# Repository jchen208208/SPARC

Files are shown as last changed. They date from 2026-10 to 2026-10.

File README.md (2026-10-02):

# SPARC

SPARC

SPARC (Spotify Proximity and Remote Control) is a gesture controller for music. You wave a hand over it to skip tracks, pause, or change the volume, without touching a screen or a button. We built it for times when looking at your phone is inconvenient or unsafe, mainly adjusting music while driving.

The current version is an MVP: an ESP32 on a custom PCB, a time-of-flight distance sensor, an 8-LED strip and a LiPo battery, all inside a 3D-printed case we designed in CAD.

## How it works

SPARC pairs over Bluetooth Low Energy as a HID media remote, the same kind of device as the play/pause button on a pair of headphones. It never talks to Spotify. Each gesture sends a standard media key (next, previous, play/pause, volume up, volume down) to the operating system, and the OS passes it to whatever app is playing.

So there is no app to install and no Spotify login, and you don't need Premium. It works on iOS, Android, macOS, Windows and Linux, and with any media app: Spotify, Apple Music, YouTube or a podcast player. Like headphone buttons, it keeps working with the screen off and the phone in your pocket.

The HID report descriptor only declares media keys. Off-the-shelf ESP32 HID libraries present themselves as keyboards, and iOS hides the on-screen keyboard while any keyboard is connected, so you couldn't type in any app with SPARC paired.

## Gestures

The VL53L0X sensor points up and watches a zone from about 4 cm out to 30 cm. Each gesture is a pass, where your hand moves through the zone and out again, or a hold, where it stops inside it.

- One pass skips to the next track.
- Two quick passes go to the previous track.
- Holding your hand still for a moment toggles play/pause.
- Three quick passes enter volume mode.

Next and previous fire about 0.7 seconds after your last pass, because SPARC waits to see whether another pass is coming. In volume mode, the spot where your hand settles becomes the midpoint. Raise your hand above it to turn the volume up and lower it to turn the volume down; the volume keeps stepping while you stay off-center. To leave volume mode, pull your hand out of the zone or flick it up quickly.

If something stays still within a metre of the sensor for five seconds, like a car roof or a shelf, SPARC treats it as a back wall and ends the zone just short of it. With nothing in range, it falls back to the fixed 30 cm.

## Lights

The LED strip animates each gesture. A swipe runs one way for next and the other way for previous, the whole strip pulses for play/pause, and a looping sweep shows volume changes. A separate status LED flashes on play/pause.

On an iPhone, SPARC also reads what's playing through Apple Media Service and, between gestures, uses the strip as a progress bar for the current track. Other devices don't offer that service, so they only get the gesture animations.

## Hardware

- ESP32-WROOM-32 module, soldered straight onto the PCB (no devboard)
- VL53L0X time-of-flight distance sensor on I2C
- 8-LED WS2812B (NeoPixel) stick and a status LED
- Single-cell LiPo, charged through a TP4056, regulated to 3.3 V by an AP2112K
- Power slide switch, plus Reset and BOOT buttons
- 4-pin header for a CP2102 USB-serial adapter, used for flashing

The KiCad project for PCB v2 is in `pcb/`, along with a STEP model and `sparc_pcb_v2_gerbers.zip`, the Gerbers we sent to the fab. The case is two printable parts, `enclosure/SPARC_Base.stl` and `enclosure/SPARC_Lid.stl`.

PCB v1 is kept in `pcb/v1/`. Its Reset and BOOT buttons are wired across the power rail, so pressing one shorts 3.3 V to ground and the board can only be flashed with a jumper wire. `pcb/v1/PCB_V1_NOTES.md` covers that workaround and the other v1 bugs, all of which v2 fixes.

The battery level SPARC reports to your phone is hardcoded at 100%. The board doesn't measure it yet.

## Flashing

The firmware is `sketch_esp_hid_v2/sketch_esp_hid_v2.ino`. It needs the ESP32 Arduino core and three libraries: NimBLE-Arduino, Adafruit_VL53L0X and FastLED.

The sensor, LED strip and status LED sit on different pins on each board, so set `BOARD` at the top of the sketch before you build: `2` for PCB v2, `1` for PCB v1, `0` for the old perfboard. The wrong value builds fine, but the sensor and LEDs stay dead.

With the power switch on, connect a CP2102 adapter to the header (the adapter doesn't power the board), hold BOOT, tap Reset, then upload:

```bash
arduino-cli compile --fqbn esp32:esp32:esp32 --port /dev/cu.usbserial-0001 --upload sketch_esp_hid_v2
```

Then pair "SPARC" from your device's Bluetooth settings.

A BLE device stops advertising while it's connected. To pair SPARC with something else, disconnect or forget it on the current device first, or it won't show up.

## Repo layout

- `sketch_esp_hid_v2/` is the current firmware.
- `sketch_esp_hid_v1/` is the earlier HID firmware. It split the zone in two, with tracks close to the sensor and volume farther out.
- `pcb/` holds the PCB v2 design files, and `pcb/v1/` the first revision.
- `enclosure/` holds the case STLs.
- `Main.py`, `ui.py`, `core.py` and `sketch_esp/` are the old desktop app and its firmware. They're no longer used (see below).
- `Wired_version/`, `Uno_version/` and `sketch_nano/` are earlier hardware builds, kept for reference.

## History

SPARC started as an Arduino Uno with an ultrasonic sensor, wired over USB to a Python script that called the Spotify Web API. Our first design mapped hand distance straight to volume. It kept misreading where the hand was, and after about a day of fighting it we switched to discrete passes and holds. Next we went wireless with an HC-05 Bluetooth module, which took a lot of troubleshooting to keep connected on macOS, and then moved to an ESP32 so we no longer needed a separate radio. We also turned the script into a macOS app with a status screen and gesture animations, so nobody had to run it from a terminal.

The Spotify API ended up as a hard limit on the whole project. In February 2026 Spotify cut Development Mode apps to five users and started requiring the developer to have Premium, and extended quota has only been open to organizations since May 2025. We had no way to apply. So we dropped the API and the desktop app, and rebuilt SPARC as a BLE HID device. That got rid of the user cap, the Premium requirement and the app install, and it made iPhone support possible, because iOS never supported the Bluetooth Serial connection the old app depended on.

After that we moved from a breadboard to perfboard, and then to our own PCB and printed case.

A few other problems came up along the way. Early commits leaked Spotify tokens, so we moved credentials into a gitignored `.env` and purged them from history. On a cold power-up the VL53L0X is still booting when the ESP32 first talks to it, and that failure used to hang `setup()` before Bluetooth started, so the board looked dead. The firmware now retries the sensor five times and starts Bluetooth whether or not it answers.

## What's next

- Measure the battery and report the real level instead of 100%
- A pairing gesture, so switching devices doesn't mean digging through Bluetooth settings

## License

MIT

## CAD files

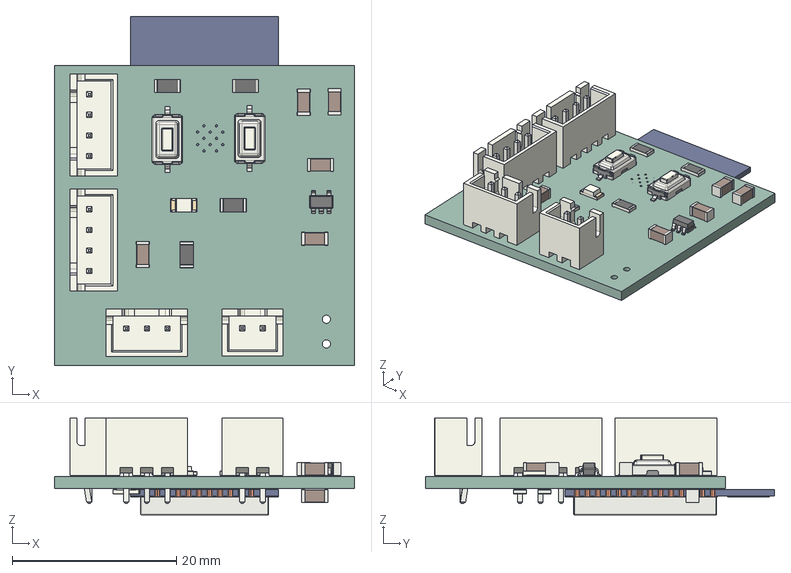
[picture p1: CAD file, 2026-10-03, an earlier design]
pcb/v2/sparc_pcb_v2.step
36.5 x 42.5 x 11.8 mm
C_1206_3216Metric x 6
SOT-23-5
R_1206_3216Metric x 6
JST_B4B_XH_A x 2
PTS636Sx25SMTRLFS x 2
JST_B2B_XH_A
LED_1206_3216Metric
JST_B3B_XH_A
ESP32-WROOM-32
spa7DBF_PCB

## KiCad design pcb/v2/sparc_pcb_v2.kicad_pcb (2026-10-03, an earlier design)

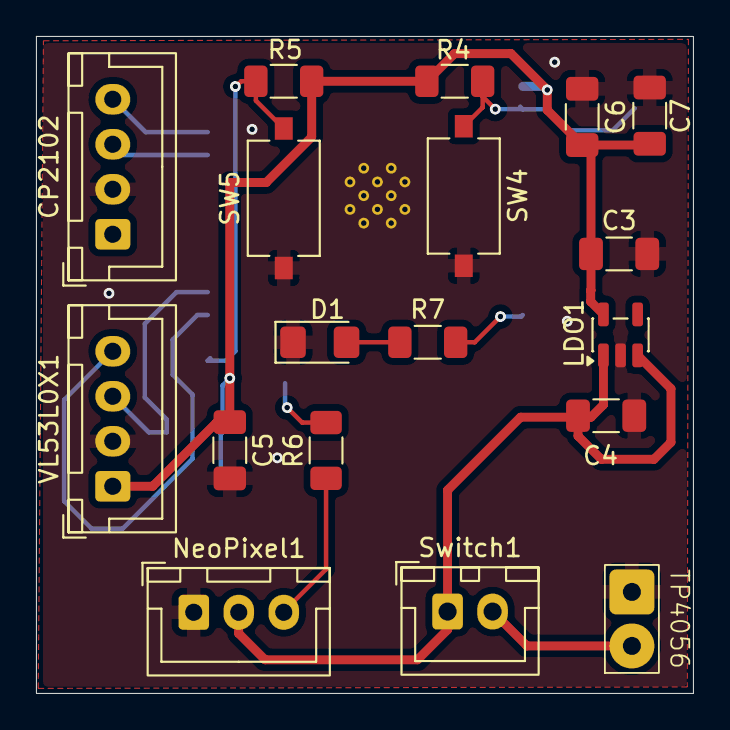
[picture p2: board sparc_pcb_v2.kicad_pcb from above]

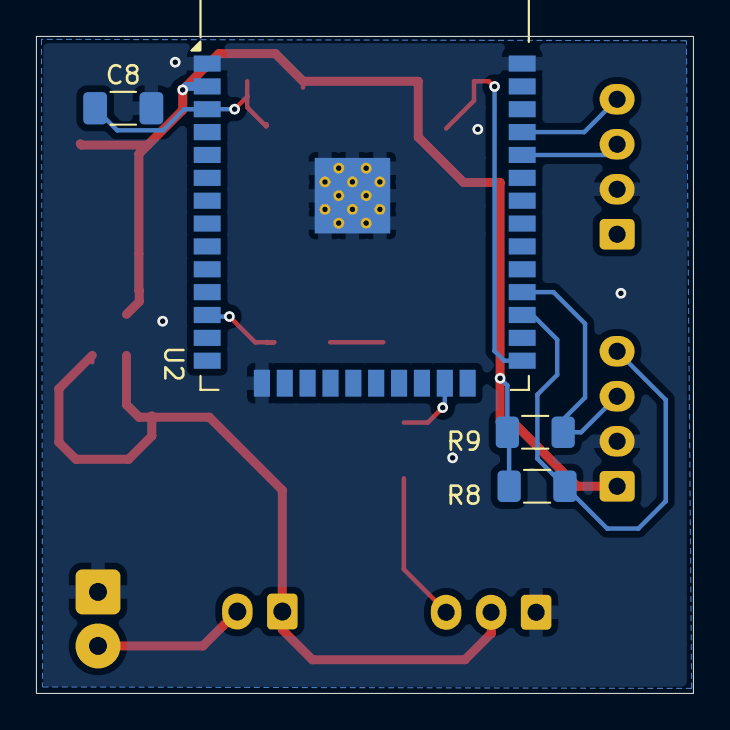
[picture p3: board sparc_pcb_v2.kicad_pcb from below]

Board: 2 copper layers, 36.5 x 36.5 mm, 22 parts (4 on the bottom side), 14 nets.

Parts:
C3, C4, C8: 1µF; C_1206_3216Metric_Pad1.33x1.80mm_HandSolder
C5, C6: 0.1µF; C_1206_3216Metric_Pad1.33x1.80mm_HandSolder
C7: 10µF; C_1206_3216Metric_Pad1.33x1.80mm_HandSolder
CP2102: JST_XH_B4B-XH-A_1x04_P2.50mm_Vertical
D1: LED; LED_1206_3216Metric_Pad1.42x1.75mm_HandSolder
LDO1: AP2112K-3.3; SOT-23-5
NeoPixel1: JST_XH_B3B-XH-A_1x03_P2.50mm_Vertical
R4, R5: 10k; R_1206_3216Metric_Pad1.30x1.75mm_HandSolder
R6, R7: 330; R_1206_3216Metric_Pad1.30x1.75mm_HandSolder
R8, R9: 4.7k; R_1206_3216Metric_Pad1.30x1.75mm_HandSolder
SW4: Reset; SW_Tactile_SPST_NO_Straight_CK_PTS636Sx25SMTRLFS
SW5: BOOT; SW_Tactile_SPST_NO_Straight_CK_PTS636Sx25SMTRLFS
Switch1: JST_XH_B2B-XH-A_1x02_P2.50mm_Vertical
TP4056: TP4056 OUT+_-
U2: ESP32-WROOM-32
VL53L0X1: JST_XH_B4B-XH-A_1x04_P2.50mm_Vertical

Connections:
+3.3V: C3.1, C5.1, C6.2, C7.1, LDO1.5 (VOUT), R4.2, R5.1, R8.1, R9.1, U2.2 (VDD), VL53L0X1.1 (+3V3)
GND: C3.2, C4.2, C5.2, C6.1, C7.2, C8.2, CP2102.2 (GND), D1.1 (K), LDO1.2 (GND), NeoPixel1.1 (GND), SW4.1, SW5.1, TP4056.4 (OUT-), U2.1 (GND), U2.15 (GND), U2.38 (GND), U2.39 (GND), VL53L0X1.2 (GND)
unnamed: CP2102.4 (RXD), U2.35 (TXD0/IO1)
unnamed: CP2102.3 (TXD), U2.34 (RXD0/IO3)
unnamed: D1.2 (A), R7.1
unnamed: NeoPixel1.3 (DIN), R6.1
unnamed: Switch1.2 (B), TP4056.1 (OUT+)
unnamed: C8.1, R4.1, SW4.2, U2.3 (EN)
unnamed: R5.2, SW5.2, U2.25 (IO0)
unnamed: R6.2, U2.23 (IO15)
unnamed: R8.2, U2.27 (IO16), VL53L0X1.4 (SDA)
unnamed: R9.2, U2.28 (IO17), VL53L0X1.3 (SCL)
unnamed: R7.2, U2.12 (IO27)
TP4056 OUT+: C4.1, LDO1.1 (VIN), LDO1.3 (EN), NeoPixel1.2 (+5V), Switch1.1 (A)

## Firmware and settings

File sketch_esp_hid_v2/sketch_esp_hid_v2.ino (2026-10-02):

// SPARC as a BLE HID media remote - no Spotify API, no companion app.
#include <NimBLEDevice.h>
#include <NimBLEHIDDevice.h>

#include <Wire.h>
#include "Adafruit_VL53L0X.h"
Adafruit_VL53L0X lox = Adafruit_VL53L0X();

#include <FastLED.h>

// defines which variables we use
#define BOARD 0  // 2 = PCB v2, 1 = PCB v1, 0 = perfboard

// preprocessor directive
#if BOARD == 2
  #define LED_PIN 15
  #define I2C_SDA 16
  #define I2C_SCL 17
  const int ledPause = 27; // status LED
  #define BATTERY_PIN 0   // TODO: confirm against PCB v2 schematic
#elif BOARD == 1
  #define LED_PIN 15
  #define I2C_SDA 17
  #define I2C_SCL 16
  const int ledPause = 27;
  #define BATTERY_PIN 0   // TODO: confirm against PCB v1 schematic
#else
  #define LED_PIN 18
  #define I2C_SDA 21
  #define I2C_SCL 22
  const int ledPause = 4;
  #define BATTERY_PIN 36   // perfboard - wire divider output here
#endif

#define NUMPIXELS 8

CRGB leds[NUMPIXELS];

// Consumer Control only - deliberately NO keyboard usage page. iOS hides the
// on-screen keyboard system-wide for anything that declares itself a keyboard,
// which would stop the user typing in every app while SPARC is connected.
static const uint8_t REPORT_ID = 1;
static uint8_t reportMap[] = {
  0x05, 0x0C,        // Usage Page (Consumer)
  0x09, 0x01,        // Usage (Consumer Control)
  0xA1, 0x01,        // Collection (Application)
  0x85, REPORT_ID,   //   Report ID (1)
  0x15, 0x00,        //   Logical Minimum (0)
  0x25, 0x01,        //   Logical Maximum (1)
  0x75, 0x01,        //   Report Size (1)
  0x95, 0x07,        //   Report Count (7)
  0x09, 0xB5,        //   Scan Next Track      -> bit 0
  0x09, 0xB6,        //   Scan Previous Track  -> bit 1
  0x09, 0xB7,        //   Stop                 -> bit 2
  0x09, 0xCD,        //   Play/Pause           -> bit 3
  0x09, 0xE2,        //   Mute                 -> bit 4
  0x09, 0xE9,        //   Volume Increment     -> bit 5
  0x09, 0xEA,        //   Volume Decrement     -> bit 6
  0x81, 0x02,        //   Input (Data, Variable, Absolute)
  0x95, 0x01,        //   Report Count (1)
  0x81, 0x03,        //   Input (Constant) - pad to a whole byte
  0xC0               // End Collection
};

const uint8_t KEY_NEXT       = 1 << 0;
const uint8_t KEY_PREV       = 1 << 1;
const uint8_t KEY_PLAY_PAUSE = 1 << 3;
const uint8_t KEY_VOL_UP     = 1 << 5;
const uint8_t KEY_VOL_DOWN   = 1 << 6;

// A zero-length press is ignored by some hosts, so hold the bit briefly.
const unsigned long KEY_HOLD_MS = 15;

NimBLEHIDDevice *hid = nullptr;
NimBLECharacteristic *inputReport = nullptr;
NimBLEServer *pServer = nullptr;
volatile bool bleConnected = false;
volatile bool authDone = false;
volatile uint16_t connHandle = 0;
bool wasConnected = false;
char peerAddr[24] = "";

// Apple Media Service: iOS pushes now-playing state to accessories over GATT - it's
// what Apple Watch uses. Unlike a volume estimate this is a closed loop, since every
// play/pause/seek re-anchors it, so drift can't accumulate. iOS only; on anything
// else discovery just fails and the strip stays in gesture-animation mode.
static const char *AMS_SERVICE       = "89D3502B-0F36-433A-8EF4-C502AD55F8DC";
static const char *AMS_ENTITY_UPDATE = "2F7CABCE-808D-411F-9A0C-BB92BA96C102";

bool amsFound = false;
int amsTries = 0;
unsigned long amsNextTry = 0;

float amsElapsed = 0;    // seconds into the track, as of amsAnchor
float amsRate = 1.0;
float amsDuration = 0;
int amsState = 0;        // 0 paused, 1 playing, 2 rewinding, 3 fast-forwarding
unsigned long amsAnchor = 0;

// Zone boundary in cm. Auto-calibrated: whatever's parked within 1m of the
// sensor for 5+ seconds becomes the "back wall," and the gesture zone runs
// from the sensor out to just short of it.
// Falls back to a fixed 30cm boundary when nothing is sitting in range.
const float DETECT_MIN = 2.0;
const float DEFAULT_ZONE_MAX = 30.0;
float zoneMax = DEFAULT_ZONE_MAX;  // Zone: DETECT_MIN..zoneMax → all gestures

// Calibration tuning
const float CALIBRATION_RANGE = 100.0;          // only consider objects within 1m
const float CALIBRATION_MIN = 10.0;             // ignore stable reads closer than this - more likely a resting hand than a backdrop
const unsigned long CALIBRATION_HOLD_MS = 5000; // must sit still this long to lock in
const float CALIBRATION_TOLERANCE = 3.0;        // cm of wobble still counted as "the same object"
const unsigned long CALIB_LOSS_MS = 1000;       // debounce before reverting to default
const float CALIBRATION_MARGIN = 0.2;           // fraction of the backdrop distance kept clear above the zone

float calibRefDist = -1;
unsigned long calibStableSince = 0;
unsigned long calibNoObjectSince = 0;
bool isCalibrated = false;

// Gesture timing
const unsigned long HOLD_TIME = 300;
const unsigned long DOUBLE_PASS_WINDOW = 800;

// Time, not sample count: the VL53L0X's blocking read paces the loop, so a fixed
// number of samples drifts with the sensor's timing budget.
// Long enough to ride out a dropout mid-wave, short enough that two quick waves are
// still seen as two passes rather than one continuous hold.
const unsigned long OUT_OF_RANGE_MS = 100;

// Non-blocking LED flash
int flashPin = -1;
unsigned long flashStart = 0;
const unsigned long FLASH_DURATION = 150;

bool handInZone = false;
unsigned long handEntryTime = 0;
bool holdFired = false;

int passCount = 0;
unsigned long firstPassExitTime = 0;

// Volume mode: entered by a pass followed immediately by a hold - skip, then
// pause. The distance at that hold becomes a fixed centre point: held farther
// away than VOLUME_DEADZONE_CM from it, the volume ramps up; held nearer than
// that, it ramps down; parked within the dead zone, the ramp pauses. It's
// level-triggered and re-evaluated every loop, so crossing back over centre -
// or reversing direction - takes effect immediately, no separate gesture
// needed. Leaving the zone at any point exits volume mode - there's no
// separate hold-to-exit.
bool volumeMode = false;
bool volumeActive = false;       // a ramp (timed VOL+/VOL- sends) is currently ticking
bool volumeUp = false;           // direction of the current ramp
unsigned long lastVolumeTick = 0;
const unsigned long VOLUME_INTERVAL = 80; // was 200 - faster ramp
float zoneEntryDist = 0;         // distance at zone entry; while in volume mode
                                  // this is the fixed centre ramp direction is
                                  // measured against (set once, never re-baselined)
float lastInZoneDist = 0;        // latest distance reading while still in zone
const float VOLUME_DEADZONE_CM = 2.0; // how far from centre before it starts ramping

// The strip can't show the host's volume - nothing comes back over HID to read, and
// an open-loop estimate desyncs the moment the user touches the volume themselves.
// It confirms gestures instead, which needs no host state and so is never wrong.
enum Anim { ANIM_NONE, ANIM_NEXT, ANIM_PREV, ANIM_PULSE, ANIM_VOL_UP, ANIM_VOL_DN, ANIM_VOL_WAIT };
Anim anim = ANIM_NONE;
unsigned long animStart = 0;
const unsigned long ANIM_STEP = 45;   // ms per LED
const unsigned long PULSE_MS = 320;
const unsigned long FRAME_MS = 20;    // cap redraws; WS2812B writes are not free
unsigned long lastFrame = 0;

// pos 0..1 along the strip, pink at the start → purple at the end. Used for the
// volume-mode "parked" indicator so it reads distinctly from the blue used
// everywhere else (track skips, the ramp comet, the progress bar).
CRGB volWaitColour(float pos) {
  int r = map(pos * 100, 0, 100, 255, 148);
  int g = map(pos * 100, 0, 100,  20,   0);
  int b = map(pos * 100, 0, 100, 147, 211);
  return CRGB(r, g, b);
}

unsigned long outOfRangeSince = 0;

// Debug: periodic Serial dump of raw distance + current zone state.
const unsigned long DEBUG_PRINT_INTERVAL = 200; // ms between prints - 5/sec is readable, doesn't flood
unsigned long lastDebugPrint = 0;

// False if the VL53L0X never came up. Gestures stop working, but Bluetooth keeps
// running so the board still pairs and looks alive, rather than going dark.
bool sensorReady = false;

float readDistanceCm() {
  if (!sensorReady) return -1;             // never poke a sensor that isn't there
  VL53L0X_RangingMeasurementData_t measure;
  lox.rangingTest(&measure, false);
  if (measure.RangeStatus != 0) return -1; // 0 is the only valid status; 1,2,3,5 return garbage
  return measure.RangeMilliMeter / 10.0;   // mm → cm
}

// Watches for something parked within 1m of the sensor. If it holds still long
// enough, that becomes the new outer edge of the gesture zone. A hand gesturing
// through never holds still for the full 5 seconds - its distance keeps
// changing, which restarts the clock below - so normal use can't trigger this,
// only something left sitting in front of the sensor (a monitor stand, a wall,
// a mug).
void updateCalibration(float current) {
  bool objectPresent = (current >= DETECT_MIN && current <= CALIBRATION_RANGE);

  if (!objectPresent) {
    // Nothing within 1m - debounce briefly (a single dropped sample shouldn't
    // undo a calibration), then fall back to the fixed default zone.
    if (calibNoObjectSince == 0) calibNoObjectSince = millis();
    if (isCalibrated && millis() - calibNoObjectSince >= CALIB_LOSS_MS) {
      zoneMax = DEFAULT_ZONE_MAX;
      isCalibrated = false;
      Serial.println("No object within 1m - zone reset to default 30cm");
    }
    calibRefDist = -1;
    calibStableSince = 0;
    return;
  }
  calibNoObjectSince = 0;

  float diff = current - calibRefDist;
  if (diff < 0) diff = -diff;

  if (calibRefDist < 0 || diff > CALIBRATION_TOLERANCE) {
    // First sighting, or it moved enough that this isn't the same dwell - restart the clock.
    calibRefDist = current;
    calibStableSince = millis();
    return;
  }

  calibRefDist = (calibRefDist * 0.9f) + (current * 0.1f); // smooth out sensor jitter

  if (millis() - calibStableSince >= CALIBRATION_HOLD_MS && calibRefDist >= CALIBRATION_MIN) {
    // Stop the gesture range short of the backdrop. Parking zoneMax on the object
    // itself put it right on the inclusive edge of inZone, so sensor jitter around
    // calibRefDist read as a hand entering and leaving the zone with nothing there -
    // spurious gestures. The margin scales with distance because so does the noise.
    // Never less than the wobble we already tolerate as "the same object", or a
    // close backdrop would sit back inside the zone again.
    float margin = calibRefDist * CALIBRATION_MARGIN;
    if (margin < CALIBRATION_TOLERANCE) margin = CALIBRATION_TOLERANCE;
    zoneMax = calibRefDist - margin;
    if (!isCalibrated) {
      isCalibrated = true;
      Serial.print("Zones calibrated to object at ");
      Serial.print(calibRefDist);
      Serial.println("cm");
    }
  }
}

void flashLed(int pin) {
  if (flashPin >= 0) digitalWrite(flashPin, LOW);
  digitalWrite(pin, HIGH);
  flashPin = pin;
  flashStart = millis();
}

void handleFlash() {
  if (flashPin >= 0 && millis() - flashStart >= FLASH_DURATION) {
    digitalWrite(flashPin, LOW);
    flashPin = -1;
  }
}

// pos 0..1 along the strip. SPARC blue: light blue at the start → dark blue at the end.
CRGB barColour(float pos) {
  int r = map(pos * 100, 0, 100, 120,   0);
  int g = map(pos * 100, 0, 100, 200,   0);
  int b = map(pos * 100, 0, 100, 255, 120);
  return CRGB(r, g, b);
}

void stripOff() {
  FastLED.clear();
  FastLED.show();
}

// AMS only pushes on change, so interpolate between updates for a smooth bar.
void renderProgress() {
  if (amsDuration < 1.0) return; // no track loaded yet

  float pos = amsElapsed;
  if (amsState == 1) pos += (millis() - amsAnchor) / 1000.0f * amsRate;
  float frac = constrain(pos / amsDuration, 0.0f, 1.0f);

  float lit = frac * NUMPIXELS;
  int full = (int)lit;
  uint8_t partial = (uint8_t)((lit - full) * 255);

  for (int i = 0; i < NUMPIXELS; i++) {
    leds[i] = barColour((float)i / (NUMPIXELS - 1));
    if (i > full)       leds[i] = CRGB::Black;
    else if (i == full) leds[i].nscale8(partial); // part-lit head keeps 8 pixels smooth
  }
  FastLED.show();
}

void startAnim(Anim a) {
  anim = a;
  animStart = millis();
}

// Non-blocking: called every loop, draws one frame and clears itself when done.
void renderAnim() {
  if (anim == ANIM_NONE) return;
  unsigned long t = millis() - animStart;

  if (anim == ANIM_VOL_WAIT) {
    // Odd and even pixels breathe against each other, one full swap per
    // second - even brightens while odd dims, then reverses. sin() gives a
    // smooth crossfade instead of a hard on/off flicker; the two levels are
    // exact opposites (phase-shifted by PI) so total brightness stays roughly
    // constant as it swaps.
    const unsigned long VOL_WAIT_PERIOD_MS = 1000;
    float phase = (t % VOL_WAIT_PERIOD_MS) / (float)VOL_WAIT_PERIOD_MS; // 0..1
    float evenLevel = (sin(2 * PI * phase) + 1.0f) / 2.0f;              // 0..1
    float oddLevel  = 1.0f - evenLevel;

    for (int i = 0; i < NUMPIXELS; i++) {
      leds[i] = volWaitColour((float)i / (NUMPIXELS - 1));
      float level = (i % 2 == 0) ? evenLevel : oddLevel;
      leds[i].nscale8((uint8_t)(level * 255));
    }
    FastLED.show();
    return; // still non-expiring - just cycles until volumeMode/volumeActive changes
  }

  if (anim == ANIM_PULSE) {
    if (t >= PULSE_MS) { anim = ANIM_NONE; stripOff(); return; }
    uint8_t fade = 255 - (t * 255 / PULSE_MS);
    for (int i = 0; i < NUMPIXELS; i++) {
      leds[i] = barColour((float)i / (NUMPIXELS - 1));
      leds[i].nscale8(fade);
    }
    FastLED.show();
    return;
  }

  unsigned long frame = t / ANIM_STEP;
  bool looping = (anim == ANIM_VOL_UP || anim == ANIM_VOL_DN);
  if (!looping && frame >= NUMPIXELS) { anim = ANIM_NONE; stripOff(); return; }

  int head = frame % NUMPIXELS;
  if (anim == ANIM_PREV || anim == ANIM_VOL_DN) head = NUMPIXELS - 1 - head;

  for (int i = 0; i < NUMPIXELS; i++) {
    int behind = (anim == ANIM_PREV || anim == ANIM_VOL_DN) ? i - head : head - i;
    if (behind >= 0 && behind < 3) {          // lit head plus a short tail
      leds[i] = looping ? volWaitColour((float)i / (NUMPIXELS - 1))
                         : barColour((float)i / (NUMPIXELS - 1));
      leds[i].nscale8(255 >> (behind * 2));
    } else {
      leds[i] = CRGB::Black;
    }
  }
  FastLED.show();
}

// Press and release. Leaving a bit set reads as a stuck key - for volume the
// host would auto-repeat forever.
void sendMediaKey(uint8_t mask, const char *label) {
  if (!bleConnected || inputReport == nullptr) return;

  uint8_t v = mask;
  inputReport->setValue(&v, 1);
  inputReport->notify();
  delay(KEY_HOLD_MS);
  v = 0;
  inputReport->setValue(&v, 1);
  inputReport->notify();

  Serial.print("SENT: ");
  Serial.println(label);
}

// Notification payload: [EntityID][AttributeID][flags][value as UTF-8].
void amsNotify(NimBLERemoteCharacteristic *chr, uint8_t *data, size_t len, bool isNotify) {
  if (len < 3) return;

  char buf[48];
  size_t n = len - 3;
  if (n >= sizeof(buf)) n = sizeof(buf) - 1;
  memcpy(buf, data + 3, n);
  buf[n] = '\0';

  if (data[0] == 0 && data[1] == 1) {        // Player / PlaybackInfo
    // "state,rate,elapsed" - any field may arrive empty, so keep the last known value.
    char *f[3] = {buf, nullptr, nullptr};
    int nf = 1;
    for (char *c = buf; *c && nf < 3; c++) {
      if (*c == ',') { *c = '\0'; f[nf++] = c + 1; }
    }
    if (f[0] && *f[0]) amsState   = atoi(f[0]);
    if (f[1] && *f[1]) amsRate    = atof(f[1]);
    if (f[2] && *f[2]) amsElapsed = atof(f[2]);
    amsAnchor = millis();
  } else if (data[0] == 2 && data[1] == 3) { // Track / Duration
    amsDuration = atof(buf);
  }
}
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
void loop() {
  if (bleConnected && !wasConnected) {
    wasConnected = true;
    Serial.print("BLE connected: ");
    Serial.println(peerAddr);
  } else if (!bleConnected && wasConnected) {
    digitalWrite(ledPause, LOW);
    anim = ANIM_NONE;
    stripOff();
    flashPin = -1;
    resetGestureState();
    handInZone = false;
    outOfRangeSince = 0;
    zoneMax = DEFAULT_ZONE_MAX;
    calibRefDist = -1;
    calibStableSince = 0;
    calibNoObjectSince = 0;
    isCalibrated = false;
    wasConnected = false;
    Serial.println("BLE disconnected");
  }

  float current = readDistanceCm();
  updateCalibration(current);

  if (millis() - lastDebugPrint >= DEBUG_PRINT_INTERVAL) {
    lastDebugPrint = millis();
    Serial.print("dist=");
    if (current < 0) Serial.print("--");
    else Serial.print(current);
    Serial.print("cm  zone=0-");
    Serial.print(zoneMax);
    Serial.print(isCalibrated ? "  [calibrated]" : "  [default]");
    Serial.print(bleConnected ? "" : "  (not connected)");
    Serial.println();
  }

  if (millis() - lastBatteryCheck >= BATTERY_CHECK_INTERVAL) {
    lastBatteryCheck = millis();
    uint8_t pct = readBatteryPercent();
    if (pct != lastBatteryPercent) {
      lastBatteryPercent = pct;
      hid->setBatteryLevel(pct);
      Serial.printf("Battery: %d%%\n", pct);
    }
  }

  if (!bleConnected) return;

  if (volumeActive && millis() - lastVolumeTick >= VOLUME_INTERVAL) {
    lastVolumeTick = millis();
    sendMediaKey(volumeUp ? KEY_VOL_UP : KEY_VOL_DOWN, volumeUp ? "VOL+" : "VOL-");
  }

  // Keep the volume indicator in sync with volumeMode/volumeActive, independent
  // of the gesture state machine below (which only fires startAnim() on the
  // transitions it cares about). Purple while parked and not ramping, comet
  // while ramping, off once volume mode is exited entirely.
  if (volumeMode) {
    if (!volumeActive && anim != ANIM_VOL_WAIT) startAnim(ANIM_VOL_WAIT);
  } else if (anim == ANIM_VOL_UP || anim == ANIM_VOL_DN || anim == ANIM_VOL_WAIT) {
    anim = ANIM_NONE;
    stripOff();
  }

  // A gesture animation always wins for its ~360ms; the bar resumes underneath.
  if (millis() - lastFrame >= FRAME_MS) {
    lastFrame = millis();
    if (anim != ANIM_NONE) renderAnim();
    else if (amsFound)     renderProgress();
  }

  if (authDone && !amsFound && amsTries < 5 && millis() >= amsNextTry) {
    amsTries++;
    amsNextTry = millis() + 2000;
    setupAMS();
  }

  handleFlash();

  bool inZone = (current >= DETECT_MIN && current <= zoneMax);

  if (inZone) outOfRangeSince = 0;
  else if (outOfRangeSince == 0) outOfRangeSince = millis();
  bool handConfirmedGone = (!inZone && outOfRangeSince != 0 &&
                            millis() - outOfRangeSince >= OUT_OF_RANGE_MS);

  if (inZone && !handInZone) {
    handInZone = true;
    handEntryTime = millis();
    holdFired = false;
    zoneEntryDist = current;
    lastInZoneDist = current;
  }

  else if (handConfirmedGone && handInZone) {
    handInZone = false;
    outOfRangeSince = 0;

    if (volumeMode) {
      // Leaving the zone always exits volume mode - swipe or no swipe, ramp
      // running or not. This is the only way out now; there's no hold-to-exit.
      volumeMode = false;
      volumeActive = false;
    } else if (!holdFired) {
      // A dwell that reached HOLD_TIME was a plain play/pause hold, not a
      // pass - only handle it here if the hand left before that.
      if (passCount == 0) {
        passCount = 1;
        firstPassExitTime = millis();
      } else if (passCount == 1 && millis() - firstPassExitTime <= DOUBLE_PASS_WINDOW) {
        sendMediaKey(KEY_PREV, "PREV");
        startAnim(ANIM_PREV);
        passCount = 0;
      } else {
        passCount = 1;
        firstPassExitTime = millis();
      }
    }
  }

  else if (inZone && handInZone) {
    lastInZoneDist = current;

    // In volume mode, ramping is level-triggered off the fixed entry point,
    // not a one-off gesture: above centre by VOLUME_DEADZONE_CM it ramps up,
    // below it ramps down, and inside the dead zone it pauses - re-checked
    // every loop for as long as the hand is held there. startAnim() only
    // fires on a transition (ramp starting or reversing), not every loop,
    // since the animations are looping ones and restarting them each frame
    // would freeze them at frame zero.
    if (volumeMode) {
      float delta = lastInZoneDist - zoneEntryDist;
      bool up   = delta >= VOLUME_DEADZONE_CM;
      bool down = delta <= -VOLUME_DEADZONE_CM;

      if (up || down) {
        bool directionChanged = !volumeActive || (volumeUp != up);
        volumeUp = up;
        volumeActive = true;
        if (directionChanged) {
          lastVolumeTick = 0;
          startAnim(volumeUp ? ANIM_VOL_UP : ANIM_VOL_DN);
        }
      } else {
        volumeActive = false;
      }
    }

    if (!holdFired && millis() - handEntryTime >= HOLD_TIME) {
      holdFired = true;
      // A pass right before this hold is the "skip, then pause" combo that
      // enters volume mode. A hold with nothing preceding it is a plain
      // play/pause instead. (volumeMode is always false by the time a fresh
      // hold can fire here - leaving the zone already cleared it - so there's
      // no "hold while in volume mode" case left to handle.)
      bool comboPending = (passCount == 1 &&
                            millis() - firstPassExitTime <= DOUBLE_PASS_WINDOW);
      resetGestureState();
      if (comboPending) {
        volumeMode = true;
        // Fresh baseline right as the mode starts, so the swipe check above
        // measures movement from here, not from wherever the hand happened
        // to be when it entered the zone for this dwell.
        zoneEntryDist = current;
        lastInZoneDist = current;
      } else {
        sendMediaKey(KEY_PLAY_PAUSE, "PLAY/PAUSE");
        startAnim(ANIM_PULSE);
        flashLed(ledPause);
      }
    }
  }

  if (!handInZone && passCount == 1 && millis() - firstPassExitTime > DOUBLE_PASS_WINDOW) {
    sendMediaKey(KEY_NEXT, "NEXT");
    startAnim(ANIM_NEXT);
    passCount = 0;
  }
}

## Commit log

2026-10-03 pcb v2 --> folder
    [sparc_pcb_v2.kicad_pcb, sparc_pcb_v2.kicad_sch, sparc_pcb_v2.step]
2026-10-03 pcb v3 schematic in altium
    [SPARC_pcb.PcbDoc, SPARC_schematic.SchDoc, SPARC_v3.PrjPcb]
